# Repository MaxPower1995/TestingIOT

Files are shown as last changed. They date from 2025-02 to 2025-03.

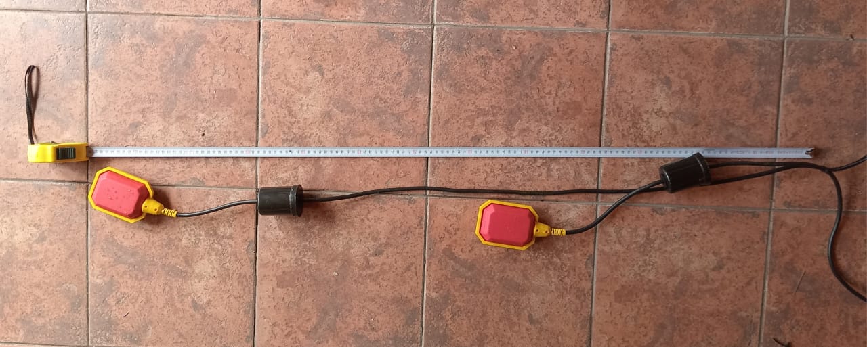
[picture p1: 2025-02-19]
Imagenes/Flotadores.jpeg

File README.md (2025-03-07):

# Modulo Zeus

# Versiones 
| Version | Fecha | Notas de la versión |
|---|---|---|
| 1.1 | 06/09/2024  | Versión de Alberto, agregue unos defines|
| 1.2 | 06/09/2024  | Arreglo el README.md |
| 1.3 | 10/10/2024 | Se cambia totalmente la logica |
| 1.4 | 26/11/2024 | Nivel de agua con flotadores |
| 1.5 | 27/11/2024 | Se agrega el aprpadeo del led |
| 1.6 | 27/11/2024 | Mayor robutez a la conexion WiFi |
| 1.7 | 29/11/2024 | Se arregla problema de prioridad en tareas |
| 1.8 | 29/11/2024 | Se agrega la lectura de los DS18B20 |
| 1.9 | 04/12/2024 | Se arregla nomenclatura de los sensores |
| 2.0 | 26/02/2025 | Server HTTP funcionando |

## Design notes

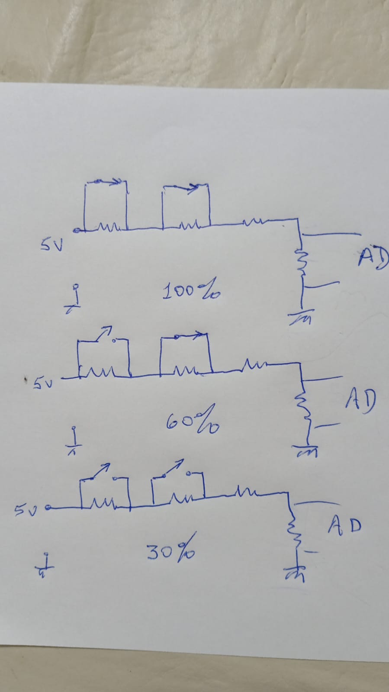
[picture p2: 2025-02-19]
Imagenes/LogicaNiveldeAguaADC.jpeg

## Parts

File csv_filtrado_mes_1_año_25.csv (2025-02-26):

Fecha | Hora | ubicacion | sensor | id | sector | estado | valor
2/1/25 | 03:39 | SE Morón | Temperatura | S3 | Temperatura Sala 2 Aires 3 y 4 | Alarmado | 27.20 °C
2/1/25 | 04:06 | SE Morón | Temperatura | S3 | Temperatura Sala 2 Aires 3 y 4 | desalarmado | 26.80 °C
2/1/25 | 04:22 | SE Morón | Temperatura | S3 | Temperatura Sala 2 Aires 3 y 4 | Alarmado | 27.20 °C
2/1/25 | 05:49 | SE Morón | Temperatura | S3 | Temperatura Sala 2 Aires 3 y 4 | desalarmado | 26.80 °C
2/1/25 | 09:02 | SE Morón | Temperatura | S3 | Temperatura Sala 2 Aires 3 y 4 | Alarmado | 27.20 °C
2/1/25 | 09:56 | SE Morón | Temperatura | S3 | Temperatura Sala 2 Aires 3 y 4 | desalarmado | 26.70 °C
2/1/25 | 10:13 | SE Morón | Temperatura | S3 | Temperatura Sala 2 Aires 3 y 4 | Alarmado | 27.20 °C
2/1/25 | 10:33 | SE Morón | Temperatura | S3 | Temperatura Sala 2 Aires 3 y 4 | desalarmado | 26.80 °C
2/1/25 | 11:20 | SE Morón | Temperatura | S3 | Temperatura Sala 2 Aires 3 y 4 | Alarmado | 27.20 °C
2/1/25 | 11:43 | SE Morón | Temperatura | S3 | Temperatura Sala 2 Aires 3 y 4 | desalarmado | 26.90 °C
2/1/25 | 11:59 | SE Morón | Temperatura | S3 | Temperatura Sala 2 Aires 3 y 4 | Alarmado | 27.20 °C
2/1/25 | 12:23 | SE Morón | Temperatura | S3 | Temperatura Sala 2 Aires 3 y 4 | desalarmado | 26.90 °C
2/1/25 | 12:39 | SE Morón | Temperatura | S3 | Temperatura Sala 2 Aires 3 y 4 | Alarmado | 27.10 °C
2/1/25 | 12:56 | SE Morón | Temperatura | S3 | Temperatura Sala 2 Aires 3 y 4 | desalarmado | 27.00 °C
2/1/25 | 13:13 | SE Morón | Temperatura | S3 | Temperatura Sala 2 Aires 3 y 4 | Alarmado | 27.30 °C
2/1/25 | 14:18 | SE Morón | Temperatura | S3 | Temperatura Sala 2 Aires 3 y 4 | desalarmado | 26.90 °C
4/1/25 | 09:16 | Ed. Libertador | Detector | S1 | ESTADO DEL GRUPO ELECTRÓGENO | Alarmado | ON
4/1/25 | 09:46 | Ed. Libertador | Detector | S1 | ESTADO DEL GRUPO ELECTRÓGENO | desalarmado | OFF
4/1/25 | 11:03 | Ed. Tronador | Detector | S1 | ESTADO DEL GRUPO ELECTRÓGENO | Alarmado | ON
4/1/25 | 11:21 | Ed. Tronador | Tensión | 24V | Voltaje Bateria | Alarmado | 28.77 V
4/1/25 | 11:32 | Ed. Tronador | Detector | S1 | ESTADO DEL GRUPO ELECTRÓGENO | desalarmado | OFF
6/1/25 | 10:39 | SE Edison | Detector | S1 | Puerta Sala de comunicaciones | Alarmado | OFF
6/1/25 | 11:58 | SE Edison | Detector | S1 | Puerta Sala de comunicaciones | desalarmado | ON
6/1/25 | 14:18 | SE Edison | Detector | S1 | Puerta Sala de comunicaciones | Alarmado | ON
6/1/25 | 23:54 | SE Morón | Tensión | Trifásica | Voltaje Fase T | Alarmado | 0.00 V
6/1/25 | 23:55 | SE Morón | Tensión | Trifásica | Voltaje fase R | Alarmado | 0.00 V
7/1/25 | 00:00 | SE Morón | Tensión | Trifásica | Voltaje Fase T | Alarmado | 0.00 V
7/1/25 | 00:00 | SE Morón | Tensión | Trifásica | Voltaje fase R | Alarmado | 0.00 V
7/1/25 | 00:02 | SE Edison | Detector | S1 | Puerta Sala de comunicaciones | Alarmado | ON
7/1/25 | 08:12 | SE San Alberto | Detector | S3 | Estado Aire Acondicionado 3 | Alarmado | OFF
7/1/25 | 09:53 | SE Morón | Detector | S3 | Estado Aire Acondicionado 3 | Alarmado | OFF
7/1/25 | 10:01 | SE San Alberto | Detector | S3 | Estado Aire Acondicionado 3 | desalarmado | ON
7/1/25 | 11:49 | SE San Alberto | Detector | S3 | Estado Aire Acondicionado 3 | Alarmado | OFF
7/1/25 | 12:17 | SE Morón | Detector | S2 | Estado Aire Acondicionado 2 | Alarmado | OFF
7/1/25 | 12:46 | SE San Alberto | Temperatura | S3 | Temperatura Sala 2 Aire 3 | Alarmado | 27.10 °C
7/1/25 | 13:10 | SE San Alberto | Detector | S3 | Estado Aire Acondicionado 3 | desalarmado | ON
7/1/25 | 13:13 | SE San Alberto | Temperatura | S3 | Temperatura Sala 2 Aire 3 | desalarmado | 26.20 °C
7/1/25 | 13:13 | SE Morón | Detector | S3 | Estado Aire Acondicionado 3 | desalarmado | ON
8/1/25 | 00:04 | SE Edison | Detector | S1 | Puerta Sala de comunicaciones | Alarmado | ON
8/1/25 | 00:04 | SE Morón | Detector | S2 | Estado Aire Acondicionado 2 | Alarmado | OFF
8/1/25 | 09:06 | SE Edison | Detector | S1 | Puerta Sala de comunicaciones | desalarmado | OFF
8/1/25 | 09:16 | SE Edison | Detector | S1 | Puerta Sala de comunicaciones | Alarmado | ON
8/1/25 | 09:33 | SE Edison | Detector | S1 | Puerta Sala de comunicaciones | desalarmado | OFF
11/1/25 | 08:08 | ED. Libertador | Detector | S1 | ESTADO DEL GRUPO ELECTRÓGENO | Alarmado | ON
11/1/25 | 08:34 | ED. Libertador | Detector | S1 | ESTADO DEL GRUPO ELECTRÓGENO | desalarmado | OFF
11/1/25 | 11:29 | SE Morón | Detector | S3 | Estado Aire Acondicionado 3 | Alarmado | OFF
11/1/25 | 11:29 | SE Morón | Detector | S4 | Estado Aire Acondicionado 4 | Alarmado | OFF
11/1/25 | 11:31 | SE Morón | Detector | S3 | Estado Aire Acondicionado 3 | desalarmado | ON
11/1/25 | 11:31 | SE Morón | Detector | S4 | Estado Aire Acondicionado 4 | desalarmado | ON
11/1/25 | 12:36 | SE Morón | Detector | S3 | Estado Aire Acondicionado 3 | Alarmado | OFF
11/1/25 | 12:36 | SE Morón | Detector | S4 | Estado Aire Acondicionado 4 | Alarmado | OFF
11/1/25 | 13:45 | SE Morón | Detector | S3 | Estado Aire Acondicionado 3 | desalarmado | ON
11/1/25 | 13:45 | SE Morón | Detector | S4 | Estado Aire Acondicionado 4 | desalarmado | ON
13/1/25 | 08:49 | SE Agronomia | Detector | S1 | ESTADO DEL GRUPO ELECTRÓGENO | Alarmado | ON
13/1/25 | 09:16 | SE Agronomia | Detector | S1 | ESTADO DEL GRUPO ELECTRÓGENO | desalarmado | OFF
13/1/25 | 17:24 | O.C. Merlo. | Tensión | Trifásica | Voltaje Fase R | Alarmado | 336.36 V
13/1/25 | 17:27 | O.C. Merlo. | Tensión | Trifásica | Voltaje Fase R | desalarmado | 389.37 V
14/1/25 | 00:25 | SE Morón | Temperatura | S3 | Temperatura Sala 2 Aires 3 y 4 | Alarmado | 27.10 °C
14/1/25 | 00:49 | SE Morón | Temperatura | S3 | Temperatura Sala 2 Aires 3 y 4 | desalarmado | 26.80 °C
14/1/25 | 01:08 | SE Morón | Temperatura | S3 | Temperatura Sala 2 Aires 3 y 4 | Alarmado | 27.20 °C
14/1/25 | 01:50 | SE Morón | Temperatura | S3 | Temperatura Sala 2 Aires 3 y 4 | desalarmado | 26.90 °C
14/1/25 | 02:06 | SE Morón | Temperatura | S3 | Temperatura Sala 2 Aires 3 y 4 | Alarmado | 27.20 °C
14/1/25 | 02:29 | SE Morón | Temperatura | S3 | Temperatura Sala 2 Aires 3 y 4 | desalarmado | 27.00 °C
14/1/25 | 02:46 | SE Morón | Temperatura | S3 | Temperatura Sala 2 Aires 3 y 4 | Alarmado | 27.10 °C
14/1/25 | 03:18 | SE Morón | Temperatura | S3 | Temperatura Sala 2 Aires 3 y 4 | desalarmado | 27.00 °C
14/1/25 | 03:34 | SE Morón | Temperatura | S3 | Temperatura Sala 2 Aires 3 y 4 | Alarmado | 27.10 °C
14/1/25 | 04:04 | SE Morón | Temperatura | S3 | Temperatura Sala 2 Aires 3 y 4 | desalarmado | 27.00 °C
14/1/25 | 04:23 | SE Morón | Temperatura | S3 | Temperatura Sala 2 Aires 3 y 4 | Alarmado | 27.60 °C
14/1/25 | 04:53 | SE Morón | Temperatura | S3 | Temperatura Sala 2 Aires 3 y 4 | desalarmado | 27.00 °C
14/1/25 | 05:10 | SE Morón | Temperatura | S3 | Temperatura Sala 2 Aires 3 y 4 | Alarmado | 27.10 °C
14/1/25 | 05:51 | SE Morón | Temperatura | S3 | Temperatura Sala 2 Aires 3 y 4 | desalarmado | 27.00 °C
14/1/25 | 06:08 | SE Morón | Temperatura | S3 | Temperatura Sala 2 Aires 3 y 4 | Alarmado | 27.10 °C
14/1/25 | 06:36 | SE Morón | Temperatura | S3 | Temperatura Sala 2 Aires 3 y 4 | desalarmado | 27.00 °C
14/1/25 | 06:53 | SE Morón | Temperatura | S3 | Temperatura Sala 2 Aires 3 y 4 | Alarmado | 27.20 °C
14/1/25 | 07:13 | SE Morón | Temperatura | S3 | Temperatura Sala 2 Aires 3 y 4 | desalarmado | 27.00 °C
14/1/25 | 07:32 | SE Morón | Temperatura | S3 | Temperatura Sala 2 Aires 3 y 4 | Alarmado | 27.10 °C
14/1/25 | 07:53 | SE Morón | Temperatura | S3 | Temperatura Sala 2 Aires 3 y 4 | desalarmado | 27.00 °C
14/1/25 | 08:09 | SE Morón | Temperatura | S3 | Temperatura Sala 2 Aires 3 y 4 | Alarmado | 27.20 °C
14/1/25 | 08:35 | SE Morón | Temperatura | S3 | Temperatura Sala 2 Aires 3 y 4 | desalarmado | 27.00 °C
14/1/25 | 08:51 | SE Morón | Temperatura | S3 | Temperatura Sala 2 Aires 3 y 4 | Alarmado | 27.10 °C
14/1/25 | 09:18 | SE Morón | Temperatura | S3 | Temperatura Sala 2 Aires 3 y 4 | desalarmado | 27.00 °C
14/1/25 | 09:35 | SE Morón | Temperatura | S3 | Temperatura Sala 2 Aires 3 y 4 | Alarmado | 27.10 °C
14/1/25 | 13:35 | SE Morón | Detector | S3 | Estado Aire Acondicionado 3 | Alarmado | OFF
14/1/25 | 13:35 | SE Morón | Detector | S4 | Estado Aire Acondicionado 4 | Alarmado | OFF
14/1/25 | 18:49 | SE Malaver | Temperatura | S3 | Temperatura Ambiente | Alarmado | 27.10 °C
14/1/25 | 19:31 | SE Malaver | Temperatura | S3 | Temperatura Ambiente | desalarmado | 26.80 °C
14/1/25 | 20:11 | SE Morón | Tensión | Trifásica | Voltaje Fase S | Alarmado | 0.00 V
14/1/25 | 20:12 | SE Morón | Tensión | Trifásica | Voltaje Fase T | Alarmado | 0.00 V
14/1/25 | 20:12 | SE Morón | Tensión | Trifásica | Voltaje fase R | Alarmado | 0.00 V
14/1/25 | 21:39 | SE Morón | Tensión | Trifásica | Voltaje Fase T | desalarmado | 398.54 V
14/1/25 | 21:39 | SE Morón | Tensión | Trifásica | Voltaje fase R | desalarmado | 393.18 V
14/1/25 | 21:40 | SE Morón | Tensión | Trifásica | Voltaje Fase S | desalarmado | 388.67 V
15/1/25 | 16:44 | SE Malaver | Temperatura | S3 | Temperatura Ambiente | Alarmado | 27.10 °C
16/1/25 | 00:00 | SE Malaver | Temperatura | S3 | Temperatura Ambiente | Alarmado | 27.10 °C
16/1/25 | 01:25 | SE Malaver | Temperatura | S3 | Temperatura Ambiente | desalarmado | 27.00 °C
18/1/25 | 09:32 | ED. Tronador | Detector | S1 | ESTADO DEL GRUPO ELECTRÓGENO | desalarmado | OFF
20/1/25 | 09:11 | SE San Alberto | Detector | S1 | Estado Aire Acondicionado 1 | Alarmado | OFF
20/1/25 | 09:11 | SE San Alberto | Detector | S3 | Estado Aire Acondicionado 3 | Alarmado | OFF
20/1/25 | 12:53 | SE San Alberto | Detector | S1 | Estado Aire Acondicionado 1 | desalarmado | ON
20/1/25 | 12:53 | SE San Alberto | Detector | S3 | Estado Aire Acondicionado 3 | desalarmado | ON
24/1/25 | 08:29 | SE San Alberto | Detector | S3 | Estado Aire Acondicionado 3 | Alarmado | OFF
24/1/25 | 08:58 | SE San Alberto | Detector | S3 | Estado Aire Acondicionado 3 | desalarmado | ON

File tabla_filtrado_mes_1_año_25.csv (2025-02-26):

fecha_inicio | hora_inicio | fecha_fin | hora_fin | ubicacion | sensor | id | sector | valor_inicio | valor_fin
02/01/25 | 03:39 | 02/01/25 | 14:18 | SE Morón | Temperatura | S3 | Temperatura Sala 2 Aires 3 y 4 | 27.20 °C | 26.90 °C
04/01/25 | 09:16 | 04/01/25 | 09:46 | Ed. Libertador | Detector | S1 | ESTADO DEL GRUPO ELECTRÓGENO | ON | OFF
04/01/25 | 11:03 | 04/01/25 | 11:32 | Ed. Tronador | Detector | S1 | ESTADO DEL GRUPO ELECTRÓGENO | ON | OFF
06/01/25 | 10:39 | 06/01/25 | 11:58 | SE Edison | Detector | S1 | Puerta Sala de comunicaciones | OFF | ON
07/01/25 | 08:12 | 07/01/25 | 13:10 | SE San Alberto | Detector | S3 | Estado Aire Acondicionado 3 | OFF | ON
07/01/25 | 12:46 | 07/01/25 | 13:13 | SE San Alberto | Temperatura | S3 | Temperatura Sala 2 Aire 3 | 27.10 °C | 26.20 °C
07/01/25 | 09:53 | 07/01/25 | 13:13 | SE Morón | Detector | S3 | Estado Aire Acondicionado 3 | OFF | ON
07/01/25 | 00:00 | N/A | N/A | SE Edison | Detector | S1 | Puerta Sala de comunicaciones | ON | N/A
08/01/25 | 00:00 | 08/01/25 | 09:33 | SE Edison | Detector | S1 | Puerta Sala de comunicaciones | ON | OFF
11/01/25 | 08:08 | 11/01/25 | 08:34 | ED. Libertador | Detector | S1 | ESTADO DEL GRUPO ELECTRÓGENO | ON | OFF
11/01/25 | 11:29 | 11/01/25 | 13:45 | SE Morón | Detector | S3 | Estado Aire Acondicionado 3 | OFF | ON
11/01/25 | 11:29 | 11/01/25 | 13:45 | SE Morón | Detector | S4 | Estado Aire Acondicionado 4 | OFF | ON
13/01/25 | 08:49 | 13/01/25 | 09:16 | SE Agronomia | Detector | S1 | ESTADO DEL GRUPO ELECTRÓGENO | ON | OFF
13/01/25 | 17:24 | 13/01/25 | 17:27 | O.C. Merlo. | Tensión | Trifásica | Voltaje Fase R | 336.36 V | 389.37 V
14/01/25 | 00:25 | 14/01/25 | 09:18 | SE Morón | Temperatura | S3 | Temperatura Sala 2 Aires 3 y 4 | 27.10 °C | 27.00 °C
14/01/25 | 18:49 | 14/01/25 | 19:31 | SE Malaver | Temperatura | S3 | Temperatura Ambiente | 27.10 °C | 26.80 °C
06/01/25 | 23:54 | N/A | N/A | SE Morón | Tensión | Trifásica | Voltaje Fase T | 0.00 V | N/A
07/01/25 | 00:00 | N/A | N/A | SE Morón | Tensión | Trifásica | Voltaje Fase T | 0.00 V | N/A
08/01/25 | 00:00 | N/A | N/A | SE Morón | Tensión | Trifásica | Voltaje Fase T | 0.00 V | N/A
09/01/25 | 00:00 | N/A | N/A | SE Morón | Tensión | Trifásica | Voltaje Fase T | 0.00 V | N/A
10/01/25 | 00:00 | N/A | N/A | SE Morón | Tensión | Trifásica | Voltaje Fase T | 0.00 V | N/A
11/01/25 | 00:00 | N/A | N/A | SE Morón | Tensión | Trifásica | Voltaje Fase T | 0.00 V | N/A
12/01/25 | 00:00 | N/A | N/A | SE Morón | Tensión | Trifásica | Voltaje Fase T | 0.00 V | N/A
13/01/25 | 00:00 | N/A | N/A | SE Morón | Tensión | Trifásica | Voltaje Fase T | 0.00 V | N/A
14/01/25 | 00:00 | 14/01/25 | 21:39 | SE Morón | Tensión | Trifásica | Voltaje Fase T | 0.00 V | 398.54 V
06/01/25 | 23:55 | N/A | N/A | SE Morón | Tensión | Trifásica | Voltaje fase R | 0.00 V | N/A
07/01/25 | 00:00 | N/A | N/A | SE Morón | Tensión | Trifásica | Voltaje fase R | 0.00 V | N/A
08/01/25 | 00:00 | N/A | N/A | SE Morón | Tensión | Trifásica | Voltaje fase R | 0.00 V | N/A
09/01/25 | 00:00 | N/A | N/A | SE Morón | Tensión | Trifásica | Voltaje fase R | 0.00 V | N/A
10/01/25 | 00:00 | N/A | N/A | SE Morón | Tensión | Trifásica | Voltaje fase R | 0.00 V | N/A
11/01/25 | 00:00 | N/A | N/A | SE Morón | Tensión | Trifásica | Voltaje fase R | 0.00 V | N/A
12/01/25 | 00:00 | N/A | N/A | SE Morón | Tensión | Trifásica | Voltaje fase R | 0.00 V | N/A
13/01/25 | 00:00 | N/A | N/A | SE Morón | Tensión | Trifásica | Voltaje fase R | 0.00 V | N/A
14/01/25 | 00:00 | 14/01/25 | 21:39 | SE Morón | Tensión | Trifásica | Voltaje fase R | 0.00 V | 393.18 V
14/01/25 | 20:11 | 14/01/25 | 21:40 | SE Morón | Tensión | Trifásica | Voltaje Fase S | 0.00 V | 388.67 V
15/01/25 | 16:44 | N/A | N/A | SE Malaver | Temperatura | S3 | Temperatura Ambiente | 27.10 °C | N/A
16/01/25 | 00:00 | 16/01/25 | 01:25 | SE Malaver | Temperatura | S3 | Temperatura Ambiente | 27.10 °C | 27.00 °C
20/01/25 | 09:11 | 20/01/25 | 12:53 | SE San Alberto | Detector | S1 | Estado Aire Acondicionado 1 | OFF | ON
20/01/25 | 09:11 | 20/01/25 | 12:53 | SE San Alberto | Detector | S3 | Estado Aire Acondicionado 3 | OFF | ON
24/01/25 | 08:29 | 24/01/25 | 08:58 | SE San Alberto | Detector | S3 | Estado Aire Acondicionado 3 | OFF | ON
04/01/25 | 11:21 | N/A | N/A | Ed. Tronador | Tensión | 24V | Voltaje Bateria | 28.77 V | N/A
07/01/25 | 12:17 | N/A | N/A | SE Morón | Detector | S2 | Estado Aire Acondicionado 2 | OFF | N/A
14/01/25 | 13:35 | N/A | N/A | SE Morón | Detector | S3 | Estado Aire Acondicionado 3 | OFF | N/A
14/01/25 | 13:35 | N/A | N/A | SE Morón | Detector | S4 | Estado Aire Acondicionado 4 | OFF | N/A

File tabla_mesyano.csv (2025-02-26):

Fecha Inicio | Hora Inicio | Fecha Fin | Hora Fin | ubicacion | sensor | id | sector | valor
11/1/25 | 08:08 | 11/1/25 | 08:34 | ED. Libertador | Detector | S1 | ESTADO DEL GRUPO ELECTRÓGENO | ON
4/1/25 | 09:16 | 4/1/25 | 09:46 | Ed. Libertador | Detector | S1 | ESTADO DEL GRUPO ELECTRÓGENO | ON
4/1/25 | 11:03 | 4/1/25 | 11:32 | Ed. Tronador | Detector | S1 | ESTADO DEL GRUPO ELECTRÓGENO | ON
4/1/25 | 11:21 | - | - | Ed. Tronador | Tensión | 24V | Voltaje Bateria | 28.77 V
13/1/25 | 17:24 | 13/1/25 | 17:27 | O.C. Merlo. | Tensión | Trifásica | Voltaje Fase R | 336.36 V
13/1/25 | 08:49 | 13/1/25 | 09:16 | SE Agronomia | Detector | S1 | ESTADO DEL GRUPO ELECTRÓGENO | ON
6/1/25 | 10:39 | 6/1/25 | 11:58 | SE Edison | Detector | S1 | Puerta Sala de comunicaciones | OFF
6/1/25 | 14:18 | 8/1/25 | 09:06 | SE Edison | Detector | S1 | Puerta Sala de comunicaciones | ON
7/1/25 | 00:02 | 8/1/25 | 09:33 | SE Edison | Detector | S1 | Puerta Sala de comunicaciones | ON
8/1/25 | 00:04 | - | - | SE Edison | Detector | S1 | Puerta Sala de comunicaciones | ON
8/1/25 | 09:16 | - | - | SE Edison | Detector | S1 | Puerta Sala de comunicaciones | ON
14/1/25 | 18:49 | 14/1/25 | 19:31 | SE Malaver | Temperatura | S3 | Temperatura Ambiente | 27.10 °C
15/1/25 | 16:44 | 16/1/25 | 01:25 | SE Malaver | Temperatura | S3 | Temperatura Ambiente | 27.10 °C
16/1/25 | 00:00 | - | - | SE Malaver | Temperatura | S3 | Temperatura Ambiente | 27.10 °C
7/1/25 | 12:17 | - | - | SE Morón | Detector | S2 | Estado Aire Acondicionado 2 | OFF
8/1/25 | 00:04 | - | - | SE Morón | Detector | S2 | Estado Aire Acondicionado 2 | OFF
7/1/25 | 09:53 | 7/1/25 | 13:13 | SE Morón | Detector | S3 | Estado Aire Acondicionado 3 | OFF
11/1/25 | 11:29 | 11/1/25 | 11:31 | SE Morón | Detector | S3 | Estado Aire Acondicionado 3 | OFF
11/1/25 | 12:36 | 11/1/25 | 13:45 | SE Morón | Detector | S3 | Estado Aire Acondicionado 3 | OFF
14/1/25 | 13:35 | - | - | SE Morón | Detector | S3 | Estado Aire Acondicionado 3 | OFF
11/1/25 | 11:29 | 11/1/25 | 11:31 | SE Morón | Detector | S4 | Estado Aire Acondicionado 4 | OFF
11/1/25 | 12:36 | 11/1/25 | 13:45 | SE Morón | Detector | S4 | Estado Aire Acondicionado 4 | OFF
14/1/25 | 13:35 | - | - | SE Morón | Detector | S4 | Estado Aire Acondicionado 4 | OFF
2/1/25 | 03:39 | 2/1/25 | 04:06 | SE Morón | Temperatura | S3 | Temperatura Sala 2 Aires 3 y 4 | 27.20 °C
2/1/25 | 04:22 | 2/1/25 | 05:49 | SE Morón | Temperatura | S3 | Temperatura Sala 2 Aires 3 y 4 | 27.20 °C
2/1/25 | 09:02 | 2/1/25 | 09:56 | SE Morón | Temperatura | S3 | Temperatura Sala 2 Aires 3 y 4 | 27.20 °C
2/1/25 | 10:13 | 2/1/25 | 10:33 | SE Morón | Temperatura | S3 | Temperatura Sala 2 Aires 3 y 4 | 27.20 °C
2/1/25 | 11:20 | 2/1/25 | 11:43 | SE Morón | Temperatura | S3 | Temperatura Sala 2 Aires 3 y 4 | 27.20 °C
2/1/25 | 11:59 | 2/1/25 | 12:23 | SE Morón | Temperatura | S3 | Temperatura Sala 2 Aires 3 y 4 | 27.20 °C
2/1/25 | 12:39 | 2/1/25 | 12:56 | SE Morón | Temperatura | S3 | Temperatura Sala 2 Aires 3 y 4 | 27.10 °C
2/1/25 | 13:13 | 2/1/25 | 14:18 | SE Morón | Temperatura | S3 | Temperatura Sala 2 Aires 3 y 4 | 27.30 °C
14/1/25 | 00:25 | 14/1/25 | 00:49 | SE Morón | Temperatura | S3 | Temperatura Sala 2 Aires 3 y 4 | 27.10 °C
14/1/25 | 01:08 | 14/1/25 | 01:50 | SE Morón | Temperatura | S3 | Temperatura Sala 2 Aires 3 y 4 | 27.20 °C
14/1/25 | 02:06 | 14/1/25 | 02:29 | SE Morón | Temperatura | S3 | Temperatura Sala 2 Aires 3 y 4 | 27.20 °C
14/1/25 | 02:46 | 14/1/25 | 03:18 | SE Morón | Temperatura | S3 | Temperatura Sala 2 Aires 3 y 4 | 27.10 °C
14/1/25 | 03:34 | 14/1/25 | 04:04 | SE Morón | Temperatura | S3 | Temperatura Sala 2 Aires 3 y 4 | 27.10 °C
14/1/25 | 04:23 | 14/1/25 | 04:53 | SE Morón | Temperatura | S3 | Temperatura Sala 2 Aires 3 y 4 | 27.60 °C
14/1/25 | 05:10 | 14/1/25 | 05:51 | SE Morón | Temperatura | S3 | Temperatura Sala 2 Aires 3 y 4 | 27.10 °C
14/1/25 | 06:08 | 14/1/25 | 06:36 | SE Morón | Temperatura | S3 | Temperatura Sala 2 Aires 3 y 4 | 27.10 °C
14/1/25 | 06:53 | 14/1/25 | 07:13 | SE Morón | Temperatura | S3 | Temperatura Sala 2 Aires 3 y 4 | 27.20 °C
14/1/25 | 07:32 | 14/1/25 | 07:53 | SE Morón | Temperatura | S3 | Temperatura Sala 2 Aires 3 y 4 | 27.10 °C
14/1/25 | 08:09 | 14/1/25 | 08:35 | SE Morón | Temperatura | S3 | Temperatura Sala 2 Aires 3 y 4 | 27.20 °C
14/1/25 | 08:51 | 14/1/25 | 09:18 | SE Morón | Temperatura | S3 | Temperatura Sala 2 Aires 3 y 4 | 27.10 °C
14/1/25 | 09:35 | - | - | SE Morón | Temperatura | S3 | Temperatura Sala 2 Aires 3 y 4 | 27.10 °C
6/1/25 | 23:54 | 14/1/25 | 21:39 | SE Morón | Tensión | Trifásica | Voltaje Fase T | 0.00 V
6/1/25 | 23:55 | 14/1/25 | 21:40 | SE Morón | Tensión | Trifásica | Voltaje fase R | 0.00 V
7/1/25 | 00:00 | - | - | SE Morón | Tensión | Trifásica | Voltaje Fase T | 0.00 V
7/1/25 | 00:00 | - | - | SE Morón | Tensión | Trifásica | Voltaje fase R | 0.00 V
14/1/25 | 20:11 | - | - | SE Morón | Tensión | Trifásica | Voltaje Fase S | 0.00 V
14/1/25 | 20:12 | - | - | SE Morón | Tensión | Trifásica | Voltaje Fase T | 0.00 V
14/1/25 | 20:12 | - | - | SE Morón | Tensión | Trifásica | Voltaje fase R | 0.00 V
20/1/25 | 09:11 | 20/1/25 | 12:53 | SE San Alberto | Detector | S1 | Estado Aire Acondicionado 1 | OFF
7/1/25 | 08:12 | 7/1/25 | 10:01 | SE San Alberto | Detector | S3 | Estado Aire Acondicionado 3 | OFF
7/1/25 | 11:49 | 7/1/25 | 13:10 | SE San Alberto | Detector | S3 | Estado Aire Acondicionado 3 | OFF
20/1/25 | 09:11 | 20/1/25 | 12:53 | SE San Alberto | Detector | S3 | Estado Aire Acondicionado 3 | OFF
24/1/25 | 08:29 | 24/1/25 | 08:58 | SE San Alberto | Detector | S3 | Estado Aire Acondicionado 3 | OFF
7/1/25 | 12:46 | 7/1/25 | 13:13 | SE San Alberto | Temperatura | S3 | Temperatura Sala 2 Aire 3 | 27.10 °C

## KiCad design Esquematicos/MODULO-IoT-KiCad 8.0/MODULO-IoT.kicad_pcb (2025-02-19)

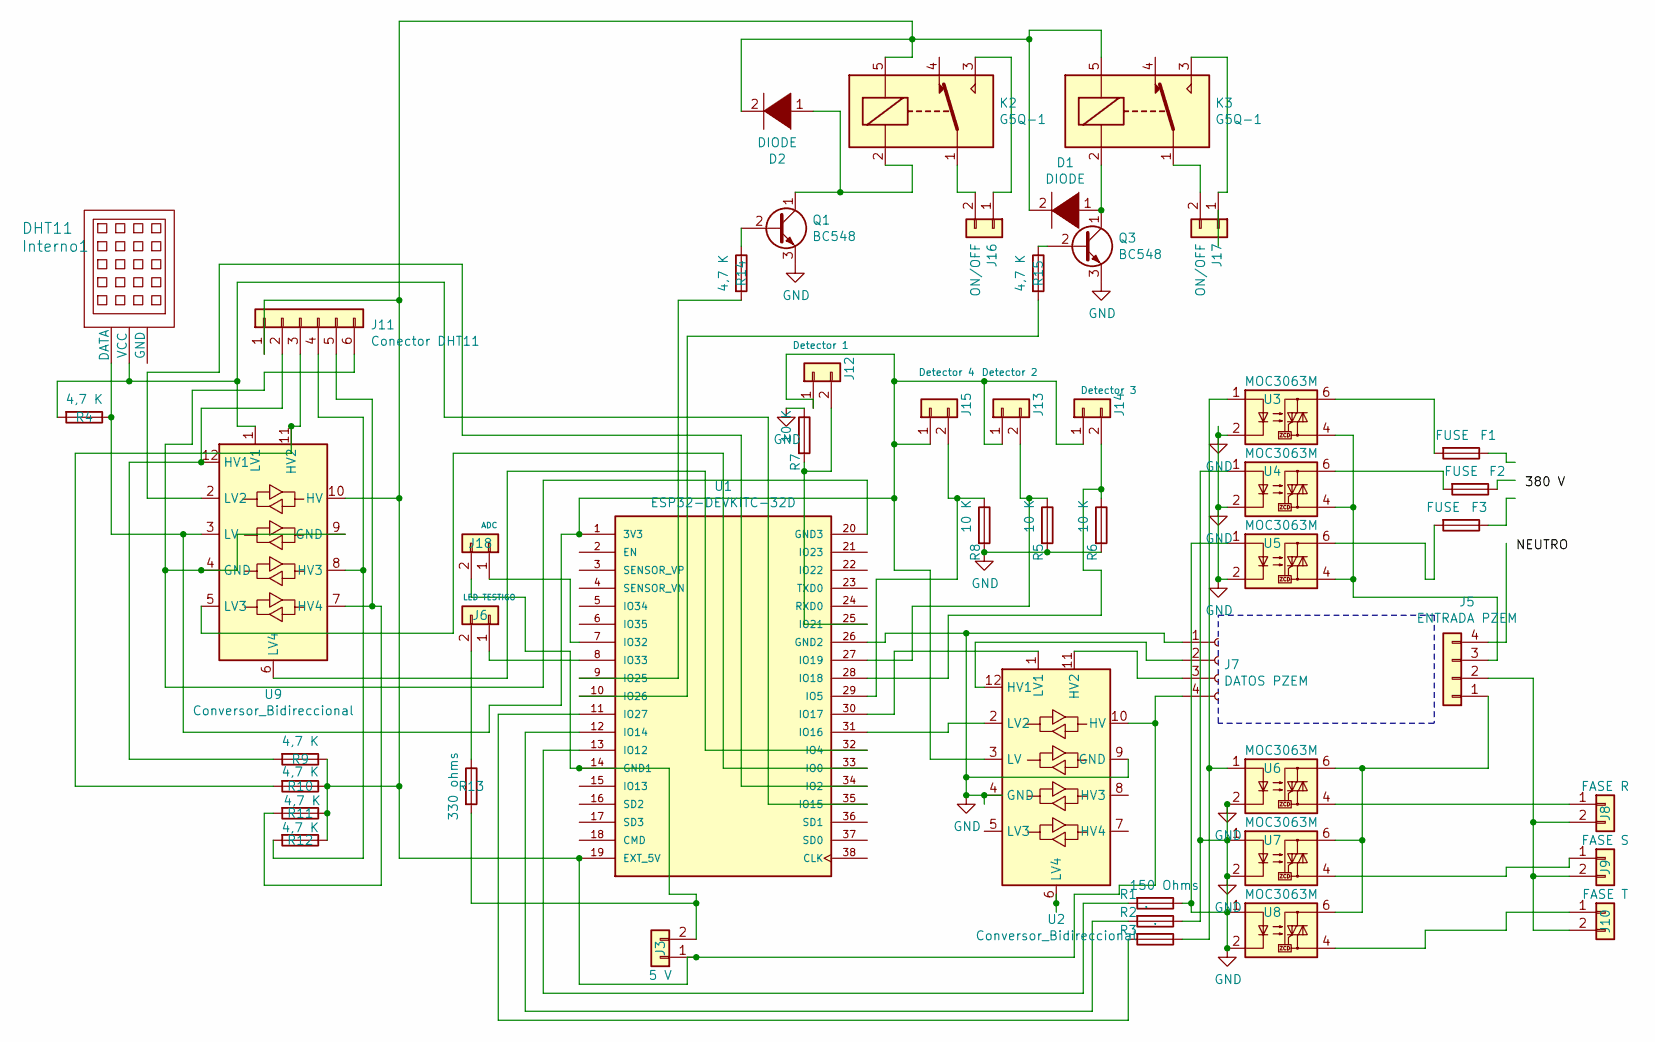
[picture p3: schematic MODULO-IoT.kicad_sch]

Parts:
D1, D2: DIODE; D_A-405_P2.54mm_Vertical_AnodeUp
F1, F2, F3: FUSE; Fuse_Bourns_MF-RG300
Interno1: DHT11; Aosong_DHT11_5.5x12.0_P2.54mm
J3: 5 V; PinHeader_1x02_P2.54mm_Vertical
J5: ENTRADA PZEM; TerminalBlock_Phoenix_MKDS-1,5-4-5.08_1x04_P5.08mm_Horizont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
J6: LED TESTIGO; PinHeader_1x02_P2.54mm_Vertical
J7: DATOS PZEM; PinHeader_1x04_P2.54mm_Vertical
J8: FASE R; TerminalBlock_Phoenix_MKDS-1,5-2-5.08_1x02_P5.08mm_Horizont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
J9: FASE S; TerminalBlock_Phoenix_MKDS-1,5-2-5.08_1x02_P5.08mm_Horizont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
J10: FASE T; TerminalBlock_Phoenix_MKDS-1,5-2-5.08_1x02_P5.08mm_Horizont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
J11: Conector DHT11; TerminalBlock_Phoenix_MKDS-1,5-6_1x06_P5.00mm_Horizontal
J12: Detector 1; TerminalBlock_Phoenix_MKDS-1,5-2-5.08_1x02_P5.08mm_Horizont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
J13: Detector 2; TerminalBlock_Phoenix_MKDS-1,5-2-5.08_1x02_P5.08mm_Horizont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
J14: Detector 3; TerminalBlock_Phoenix_MKDS-1,5-2-5.08_1x02_P5.08mm_Horizont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
J15: Detector 4; TerminalBlock_Phoenix_MKDS-1,5-2-5.08_1x02_P5.08mm_Horizont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
J16, J17: ON/OFF; TerminalBlock_Phoenix_MKDS-1,5-2-5.08_1x02_P5.08mm_Horizont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
J18: ADC; PinHeader_1x02_P2.54mm_Vertical
K2, K3: G5Q-1; Relay_SPDT_Omron-G5LE-1
Q1, Q3: BC548; TO-126-3_Vertical
R1: 150 Ohms; R_Axial_DIN0207_L6.3mm_D2.5mm_P10.16mm_Horizontal
R2, R3: .; R_Axial_DIN0207_L6.3mm_D2.5mm_P10.16mm_Horizontal
R4, R9, R10, R11, R12, R14, R15: 4,7 K; R_Axial_DIN0309_L9.0mm_D3.2mm_P5.08mm_Vertical
R5, R6, R7, R8: 10 K; R_Axial_DIN0207_L6.3mm_D2.5mm_P10.16mm_Horizontal
R13: 330 ohms; R_Axial_DIN0309_L9.0mm_D3.2mm_P5.08mm_Vertical
U1: ESP32-DEVKITC-32D; MODULE_ESP32-DEVKITC-32D
U2, U9: Conversor_Bidireccional; DIP-12_W10.16mm_LongPads
U3, U4, U5, U6, U7, U8: MOC3063M; DIP-6_W7.62mm

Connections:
GND: J7.1, Q1.3 (E), Q3.3 (E), R1.1, R2.1, R5.2, R6.2, R7.1, R8.2, U1.26 (GND2), U2.4 (GND), U2.9 (GND), U3.2, U4.1, U4.2, U5.1, U5.2, U6.2, U7.1, U7.2, U8.1, U8.2
unnamed: D1.2 (A), D2.2 (A), J3.1, J7.4, J11.1, K2.5, K3.5, R9.1, R10.1, R11.1, R12.1, U1.19 (EXT_5V), U2.10 (HV), U9.10 (HV)
unnamed: D1.1 (K), K3.2, Q3.1 (C)
unnamed: D2.1 (K), K2.2, Q1.1 (C)
unnamed: F1.2, U3.6
unnamed: F2.2, U4.6
unnamed: F3.2, U5.6
unnamed: Interno1.1 (DATA), J12.1, J13.1, J14.1, J15.1, R4.1, U1.1 (3V3), U2.3 (LV), U9.3 (LV)
unnamed: Interno1.2 (VCC), R4.2, U1.35 (IO15), U9.1 (LV1)
unnamed: J5.1, U6.6, U7.6, U8.6
unnamed: J5.3, U3.4, U4.4, U5.4
unnamed: J6.1, U1.8 (IO33)
unnamed: J6.2, R13.1
unnamed: J7.2, U2.12 (HV1)
unnamed: J7.3, U2.11 (HV2)
unnamed: J8.1, U6.4
unnamed: J9.1, U7.4
unnamed: J10.1, U8.4
unnamed: J5.2, J8.2, J9.2, J10.2
unnamed: J11.2, R9.2, U9.12 (HV1)
unnamed: J11.3, R10.2, U9.11 (HV2)
unnamed: J11.4, R12.2, U9.8 (HV3)
unnamed: J11.5, R11.2, U9.7 (HV4)
unnamed: J11.6, U1.20 (GND3), U9.4 (GND), U9.9 (GND)
unnamed: J12.2, R7.2, U1.25 (IO21)
unnamed: J13.2, R5.1, U1.27 (IO19)
unnamed: J14.2, R6.1, U1.28 (IO18)
unnamed: J15.2, R8.1, U1.29 (IO5)
unnamed: J16.1, K2.3
unnamed: J16.2, K2.1
unnamed: J17.1, K3.3
unnamed: J17.2, K3.1
unnamed: J18.1, U1.7 (IO32)
unnamed: J3.2, J18.2, R13.2, U1.14 (GND1)
unnamed: Q1.2 (B), R14.1
unnamed: Q3.2 (B), R15.1
unnamed: R3.1, U3.1, U6.1
unnamed: U1.33 (IO0), U9.5 (LV3)
unnamed: U1.34 (IO2), U9.2 (LV2)
unnamed: U1.32 (IO4), U9.6 (LV4)
unnamed: R1.2, U1.13 (IO12)
unnamed: R2.2, U1.12 (IO14)
unnamed: U1.31 (IO16), U2.2 (LV2)
unnamed: U1.30 (IO17), U2.1 (LV1)
unnamed: R14.2, U1.9 (IO25)
unnamed: R15.2, U1.10 (IO26)
unnamed: R3.2, U1.11 (IO27)

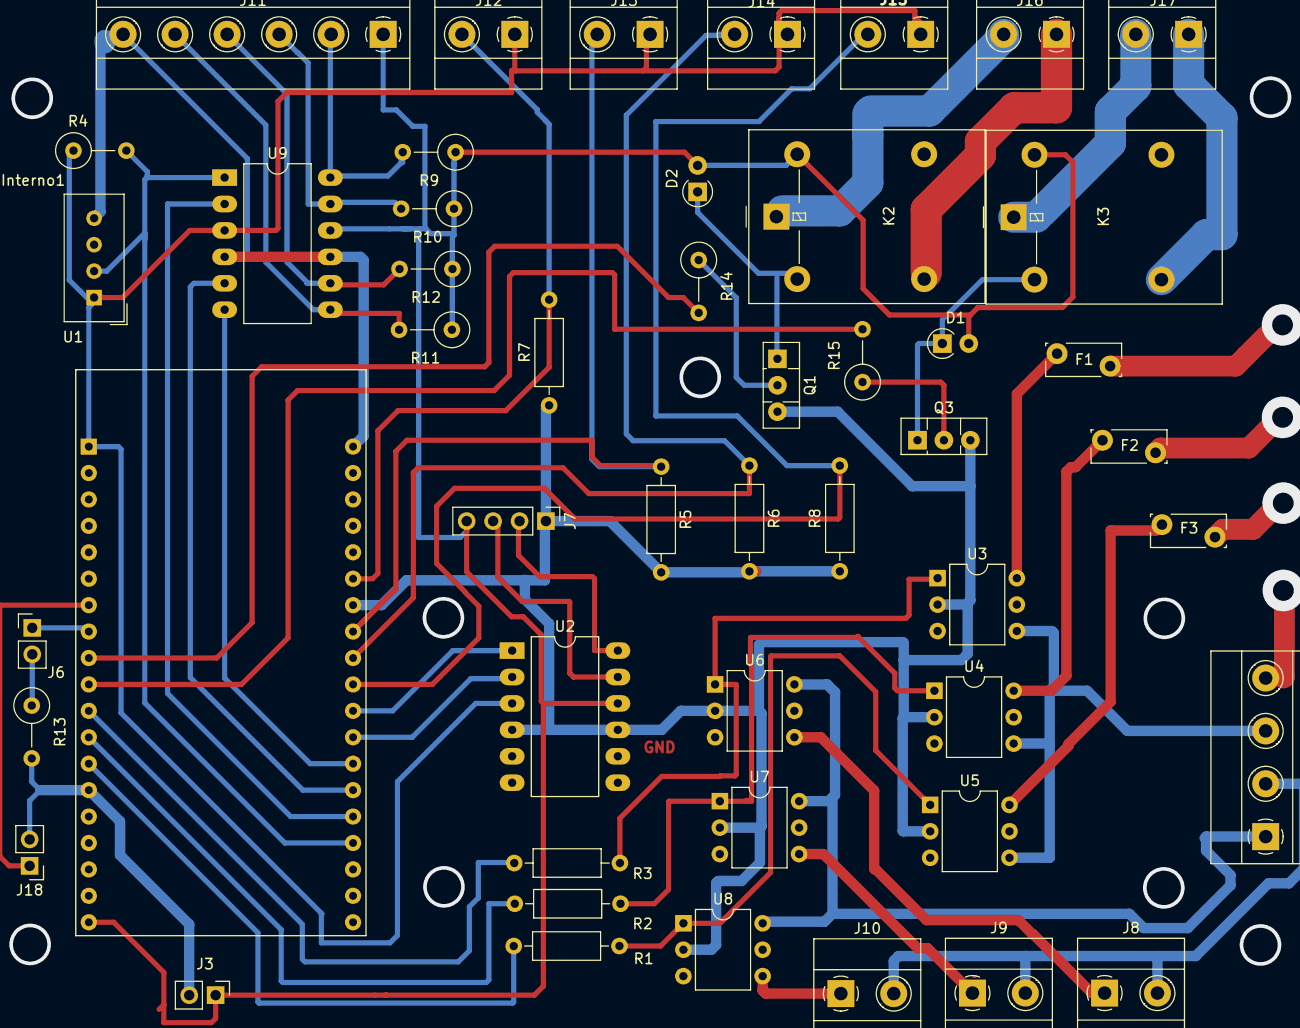
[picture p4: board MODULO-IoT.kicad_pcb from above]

Board: 2 copper layers, 49 parts (0 on the bottom side), 47 nets.

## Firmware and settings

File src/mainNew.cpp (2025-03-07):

#include <Arduino.h>
#include <WiFi.h>
#include <WebServer.h>
#include <Preferences.h>
#include "htmlpage.hpp"
#include <PubSubClient.h>
#include "DHT.h"
#include <PZEM004Tv30.h>
#include <OneWire.h>
#include <DallasTemperature.h>
#include "Adafruit_MQTT.h"
#include "Adafruit_MQTT_Client.h"
#include <string>

// Definir el GPIO para activar el modo AP
#define CONFIG_PIN 4
#define DHT1 15 //15
#define DHT2 2
#define DHT3 0
#define DHT4 4

#define DETECTOR_1 5
#define DETECTOR_2 18
#define DETECTOR_3 19
#define DETECTOR_4 21

#define DHTTYPE DHT11   // DHT 11
#define DHTTYPE2 DHT11   // DHT 11-2
#define DHTTYPE3 DHT11   // DHT 11-3
#define DHTTYPE4 DHT11   // DHT 11-4

#define PZEM_RX_PIN 16
#define PZEM_TX_PIN 17
#define PZEM_SERIAL Serial2

#define RELE_1 25
#define RELE_2 26
#define ADC_1 32
#define ADC_2 36

#define FASE_R 12
#define FASE_S 14
#define FASE_T 27
#define LED_ROJO 33

//El largo de este vector como minimo tiene que ser el tiempo de envio en segundos x2, porque leo los detectores cada 500ms
#define VECTOR_DETECTOR 250 
#define VECTOR 4
#define ERROR 0

#define RANGO_INF 0
#define RANGO_SUP 100

// HTML almacenado en un string (ya lo definimos antes)
extern const char htmlPage[];
extern WebServer server;
extern Preferences preferences;
extern Config config;  // Variable global para almacenar la configuración
PZEM004Tv30 pzem(PZEM_SERIAL, PZEM_RX_PIN, PZEM_TX_PIN);

DHT dht1(DHT1, DHTTYPE);
DHT dht2(DHT2, DHTTYPE2);
DHT dht3(DHT3, DHTTYPE3);
DHT dht4(DHT4, DHTTYPE4);

OneWire oneWire1(DHT1);
OneWire oneWire2(DHT2);
OneWire oneWire3(DHT3);
OneWire oneWire4(DHT4);

DallasTemperature sensors1(&oneWire1);
DallasTemperature sensors2(&oneWire2);
DallasTemperature sensors3(&oneWire3);
DallasTemperature sensors4(&oneWire4);

//Incluir la direccion del servidor MQTT
const char* mqtt_server = "143.198.66.52";// Broker EDENOR
//const char* mqtt_server = "143.244.186.22"; // Broker Prueba
const char* mqtt_user = "emsetec";
const char* mqtt_pass = "84705200";

//Variables para enviar datos por MQTT
const unsigned long TIEMPO_DE_ENVIO = 60000;  
const unsigned long RESET = 3600000*2;  // 1 hora en milisegundos
unsigned long ultimoEnvio = 0;  // Tiempo de la última ejecución
unsigned long tiempoActual = 0;
unsigned long tiempoReset = 0;

//Variables de Funcionamiento
float factorVoltaje = 1;
float voltaje[3] = {0,0,0};
float corriente[3] = {0,0,0};
float temperatura[4] = {0,0,0,0};
float humedad[4] = {0,0,0,0};
float adc[4] = {0,0,0,0};
float factorBobina = 1;

int maxWifiSSID = 4;
int maxWifiRetry = 10;
String CLIENT_ID;
String EQUIPO;

#define ESP_CLIENT_NAME espClient
WiFiClient ESP_CLIENT_NAME;
PubSubClient client(ESP_CLIENT_NAME);


const char* redes[4][2] = {
    {"e-Invitados", "Edenor2022$"},
    {"EMSETEC4G", "IOT2024EMSETEC"},
    {"EMSETEC-2.4GHz", "33710081099"},
    {"HUAWEI_311_1B94", "Maxpower1995"}
  };

//Funciones
void wifiInit(const char* redes[][2], int num_redes, int max_intentos);
void lecturaPzems();
void enviarDatosMQTT();
void parpadearLed(void *pvParameters);
void reconnect();
void leerDHT11();
void leerDS18B20();
void configuracionPines();

// ########################################################################################################################
// ################## MEJORAS PARA EL SISTEMA #############################################################################
// ########################################################################################################################

// ----> Tengo que ponerle un temporizador para que no quede siempre en modo AP, nose 5 minutos
// ----> Agregar la red del laboratorio
// ----> Para seleccionar los adcs, quiza me convenga usar un if en el setup y despues un SWITCH/Diccionario
// ----> sprintf(topicBuffer, "EMSETEC/%s/SENSOR1/HUMEDAD", EQUIPO.c_str());, guardaro en un string en el setup  asi no ejecuta multiples veces lo mismo

// ########################################################################################################################
// ########################################################################################################################
// ########################################################################################################################

void setup() {
  Serial.begin(115200);
  delay(200);
  pinMode(CONFIG_PIN, INPUT_PULLUP);
  Serial.println("#######################################");
  Serial.println("    Incicializando el Sistema...");
  Serial.println("#######################################");
  loadConfiguration();
  configuracionPines();
  //printConfiguration();

  EQUIPO = "SERIE" + String(config.serialNumber);
  CLIENT_ID = "espClient"+ String(config.serialNumber);


  // Si el pin de configuración está en alto, entra en modo AP
  if (digitalRead(CONFIG_PIN) == LOW) {
    startAP();
    server.on("/", handleRoot);
    server.on("/save", handleSave);
    server.begin();
    Serial.println("Servidor web iniciado en modo AP.");
  } else {
    Serial.println("Modo normal. No se inicia configuración.");
    // Aquí podrías cargar la configuración y conectar a WiFi, etc.
    //loadConfiguration();
    //printConfiguration();
  }

  if (config.sensor == "DHT11") {
    dht1.begin();dht2.begin();
    dht3.begin();dht4.begin();
    Serial.println("Se usan: DHT11");
  } else if (config.sensor == "DS18B20") {
    sensors1.begin();sensors2.begin();
    sensors3.begin();sensors4.begin();   
    Serial.println("Se usan: DS18B20"); 
  } else {
    Serial.println("No se mide Temperatura");
  }

  if (config.conexion == "Trifasica") {
    factorVoltaje = sqrt(3);
    Serial.println("Se mide tension Trifásica");
  } else if (config.conexion == "Monofasica") {
    factorVoltaje = 1; 
    Serial.println("Se mide tension Monofásica");
  } else {
    Serial.println("No se mide Tensión");
  }

  factorBobina = config.factor;
  Serial.print("Factor de Bobina: ");
  Serial.println(factorBobina);

  // Imprime el valor del define
  Serial.print("Este es el Modulo: ");
  Serial.println(EQUIPO);
  Serial.print("Con el Cliente: ");
  Serial.println(CLIENT_ID);

  if (strcmp(mqtt_server, "143.198.66.52") == 0) {
    Serial.println("Conectado al Broker de EDENOR");
  } else {
    Serial.println("Conectado al Broker de PRUEBAS");
  }
  
  client.setServer(mqtt_server, 1884);
  //xTaskCreate(leerDetectores,"Leer Detectores",4096,NULL,1,NULL);
  xTaskCreate(parpadearLed, "Blink Task", 4096, NULL, 0, NULL);
  //resetVectorDetectores();
  //analogReadResolution(12);
  Serial.println("#######################################");
  Serial.println("        Sistema Configurado");
  Serial.println("#######################################");
}


void loop() {
  tiempoReset = millis();
  if(tiempoReset >= RESET){
    ESP.restart();
  }
  tiempoActual = millis();

  if (WiFi.getMode() == WIFI_AP) {
    server.handleClient();
  }else{
    // Aquí el resto de la lógica del dispositivo...
    if (WiFi.status() != WL_CONNECTED) {
      wifiInit(redes, maxWifiSSID, maxWifiRetry);
    }

    Serial.println("Leyendo los Pzems");
    lecturaPzems();
    if (config.sensor == "DHT11") {
      leerDHT11();
      Serial.println("Leyendo DHT11");
    } else if (config.sensor == "DS18B20") {
      leerDS18B20(); 
      Serial.println("Leyendo DS18B20"); 
    } else {
      Serial.println("No se mide Temperatura");
    }
    enviarDatosMQTT();
  }


// ------------ Automatizaciones ADC 1 ------------
  if (config.adc1 == "Combustible") {
    Serial.println("Se lee Combustible en el ADC1");
    adc[0] = analogRead(ADC_1);
  } else if (config.adc1 == "Bateria 12") {
    Serial.println("Se lee Bateria 12V en el ADC1");
    adc[0] = analogRead(ADC_1);
  } else if (config.adc1 == "Bateria 24") {
    Serial.println("Se lee Bateria 24V en el ADC1");
    adc[0] = analogRead(ADC_1);
  } else if (config.adc1 == "Nivel Inundacion") {
    Serial.println("Se lee Bateria 36V en el ADC1");
    adc[0] = analogRead(ADC_1);
  }else {
    Serial.println("No se mide ADC1");
  }

// ------------ Automatizaciones ADC 2 ------------
  if (config.adc2 == "Combustible") {
    Serial.println("Se lee Combustible en el ADC2");
    adc[0] = analogRead(ADC_2);
  } else if (config.adc2 == "Bateria 12") {
    Serial.println("Se lee Bateria 12V en el ADC2");
    adc[0] = analogRead(ADC_2);
  } else if (config.adc2 == "Bateria 24") {
    Serial.println("Se lee Bateria 24V en el ADC2");
    adc[0] = analogRead(ADC_2);
  } else if (config.adc2 == "Nivel Inundacion") {
    Serial.println("Se lee Bateria 36V en el ADC1");
    adc[0] = analogRead(ADC_2);
  }else {
    Serial.println("No se mide ADC2");
  }

}

  //---------------- VOID CONECTAR WiFi -------------------
void wifiInit(const char* redes[][2], int numRedes, int max_intentos) {
  Serial.println("Iniciando conexión WiFi...");
  bool conectado = false;
  preferences.begin("wifi", false); // Iniciar NVS para guardar/leer datos

  String last_ssid = preferences.getString("last_ssid", "");
  String last_password = preferences.getString("last_password", "");
  preferences.end();

  

  // Si hay una red guardada, intenta conectarte primero a ella
  if (last_ssid != "") {
    Serial.print("Intentando con la última red guardada: ");
    Serial.print(last_ssid);

    WiFi.begin(last_ssid.c_str(), last_password.c_str());

    for (int i = 0; i < max_intentos; i++) {
      if (WiFi.status() == WL_CONNECTED) {
        conectado = true;
        break;
      }
      delay(500);
      Serial.print(".");
    }

    if (conectado) {
      Serial.println("\nConectado a la última red guardada.");
      Serial.print("IP: ");
      Serial.println(WiFi.localIP());
      return;
    } else {
      Serial.println("\nNo se pudo conectar a la última red guardada.");
    }
  }

  //Intenta conectarse a la red que se le cargo por formulario HTML
  Serial.print("Intentando conectar a: ");
  Serial.println(config.wifiSSID);
  WiFi.begin(config.wifiSSID, config.wifiPassword);
  for (int j = 0; j < max_intentos; j++) {
    if (WiFi.status() == WL_CONNECTED) {
      conectado = true;

      // Guardar esta red en NVS
      preferences.begin("wifi", false);
      preferences.putString("last_ssid", config.wifiSSID);
      preferences.putString("last_password", config.wifiPassword);
      preferences.end();

      Serial.println("\nConexión exitosa.");
      Serial.print("IP: ");
      Serial.println(WiFi.localIP());
      return;
    }
    delay(500);
    Serial.print(".");
  }

  // Intentar conectarse con las redes del vector
  for (int i = 0; i < numRedes; i++) {
    const char* ssid = redes[i][0];
    const char* password = redes[i][1];

    Serial.print("Intentando conectar a redes standars: ");
    Serial.println(ssid);

    WiFi.begin(ssid, password);

    for (int j = 0; j < max_intentos; j++) {
      if (WiFi.status() == WL_CONNECTED) {
        conectado = true;

        // Guardar esta red en NVS
        preferences.begin("wifi", false);
        preferences.putString("last_ssid", ssid);
        preferences.putString("last_password", password);
        preferences.end();

        Serial.println("\nConexión exitosa.");
        Serial.print("IP: ");
        Serial.println(WiFi.localIP());
        return;
      }
      delay(500);
      Serial.print(".");
    }

    if (!conectado) {
      Serial.println("\nNo se pudo conectar a esta red.");
    }
  }

  // Si no se conecta a ninguna red, reinicia el ESP32
  Serial.println("Error: No se pudo conectar a ninguna red, reiniciando...");
  ESP.restart();
}

void configuracionPines(){
  pinMode(FASE_R, OUTPUT); // D1 salida digital activa optoacopladores 
  digitalWrite(FASE_R, HIGH);
  pinMode(FASE_S, OUTPUT); // D6 salida digital activa optoacopladores
  digitalWrite(FASE_S, HIGH);
  pinMode(FASE_T, OUTPUT); // D5 salida digital activa optoacopladores
  digitalWrite(FASE_T, HIGH);
  pinMode(LED_ROJO, OUTPUT); // Sensor encendido
  pinMode(DETECTOR_1, OUTPUT); //  Detector 1
  digitalWrite(DETECTOR_1, LOW);
  pinMode(DETECTOR_2, OUTPUT); // Detector 2
  digitalWrite(DETECTOR_2, LOW);
  pinMode(DETECTOR_3, OUTPUT); // Detector 3
  digitalWrite(DETECTOR_3, LOW);
  pinMode(DETECTOR_4, OUTPUT); // Detector 4
  digitalWrite(DETECTOR_4, LOW);
  pinMode(RELE_1, OUTPUT); // RELE
  digitalWrite(RELE_1, LOW);
  pinMode(RELE_2, OUTPUT); // RELE 2
  digitalWrite(RELE_2, LOW);
}

void parpadearLed(void *pvParameters) {
  for (;;) {
    digitalWrite(LED_ROJO,HIGH);
    vTaskDelay(1000 / portTICK_PERIOD_MS);
    digitalWrite(LED_ROJO,LOW);
    vTaskDelay(1000 / portTICK_PERIOD_MS);
  }
}

void reconnect() {
  Serial.print("Intentando conectar a MQTT...");
  if ("ESP32S2Client") {
    Serial.println("conectado");
  } else {
    Serial.print("fallo, rc=");
    Serial.print(client.state());
    ESP.restart();
    delay(5000);
  }
}

void leerDHT11(){
    temperatura[0] = dht1.readTemperature();
    humedad[0] = dht1.readHumidity();
    if(isnan(temperatura[0])){
      temperatura[0] = ERROR;
      humedad[0] = ERROR;
    }
    delay(2000);

    temperatura[1] = dht2.readTemperature();
    humedad[1] = dht2.readHumidity();
    if(isnan(temperatura[1])){
      temperatura[1] = ERROR;
      humedad[1] = ERROR;
    }
    delay(2000);

    temperatura[2] = dht3.readTemperature();
    humedad[2] = dht3.readHumidity();
    if(isnan(temperatura[2])){
      temperatura[2] = ERROR;
      humedad[2] = ERROR;
    }
    delay(2000);

    temperatura[3] = dht4.readTemperature();
    humedad[3] = dht4.readHumidity();
    if(isnan(temperatura[3])){
      temperatura[3] = ERROR;
      humedad[3] = ERROR;
    }
    delay(2000); 

    printf("Temperatura 1: %f, Humedad 1 : %f\n",temperatura[0],humedad[0]);
    printf("Temperatura 2: %f, Humedad 2 : %f\n",temperatura[1],humedad[1]);
    printf("Temperatura 3: %f, Humedad 3 : %f\n",temperatura[2],humedad[2]);
    printf("Temperatura 4: %f, Humedad 4 : %f\n",temperatura[3],humedad[3]);
  }

void leerDS18B20(){
  // Solicitar temperatura a cada sensor
  sensors1.requestTemperatures();
  sensors2.requestTemperatures();
  sensors3.requestTemperatures();
  sensors4.requestTemperatures();

  // Leer y mostrar las temperaturas
  temperatura[0] = sensors1.getTempCByIndex(0);
  temperatura[1] = sensors2.getTempCByIndex(0);
  temperatura[2] = sensors3.getTempCByIndex(0);
  temperatura[3] = sensors4.getTempCByIndex(0);

  Serial.print("Temperatura Sensor 1: ");
  Serial.println(temperatura[0]);
  Serial.print("Temperatura Sensor 2: ");
  Serial.println(temperatura[1]);
  Serial.print("Temperatura Sensor 3: ");
  Serial.println(temperatura[2]);
  Serial.print("Temperatura Sensor 4: ");
  Serial.println(temperatura[3]);
}

void lecturaPzems(){
  // ######## FASE R ########
    digitalWrite(FASE_S, HIGH);
    digitalWrite(FASE_T, HIGH);
    digitalWrite(FASE_R, HIGH);
    delay(2000);
    //pzem.resetEnergy();
    digitalWrite(FASE_R, LOW);
  
    delay(3000);
    //printf("FASE R\n");
    voltaje[0] = pzem.voltage();
    voltaje[0] = voltaje[0]*factorVoltaje;
    delay(1000);
    corriente[0] = pzem.current()*factorBobina;
  
    if(isnan(voltaje[0])){
      voltaje[0] = ERROR;
      corriente[0] = ERROR;
    }
  
    printf("Voltaje Fase R: %f \n",voltaje[0]);
    printf("Corriente Fase R: %f\n",corriente[0]);
  
  // ######## FASE S ########
    digitalWrite(FASE_S, HIGH);
    digitalWrite(FASE_T, HIGH);
    digitalWrite(FASE_R, HIGH);
    delay(2000);
    //pzem.resetEnergy();
    digitalWrite(FASE_S, LOW);
  
  
    delay(3000);
    //printf("FASE S\n");
    voltaje[1] = pzem.voltage();
    voltaje[1] = voltaje[1]*factorVoltaje;
    delay(1000);
    corriente[1] = pzem.current()*factorBobina;
  
    if(isnan(voltaje[1])){
      voltaje[1] = ERROR;
      corriente[1] = ERROR;
    }
  
    printf("Voltaje Fase S: %f\n",voltaje[1]);
    printf("Corriente Fase S: %f\n",corriente[1]);
  
  
  // ######## FASE T ########
    digitalWrite(FASE_S, HIGH);
    digitalWrite(FASE_T, HIGH);
    digitalWrite(FASE_R, HIGH);
    delay(2000);
    //pzem.resetEnergy();
    digitalWrite(FASE_T, LOW);
  
  
    delay(3000);
    //printf("FASE T\n");
    voltaje[2] = pzem.voltage();
    voltaje[2] = voltaje[2]*factorVoltaje;
    delay(1000);
    corriente[2] = pzem.current()*factorBobina;
  
    if(isnan(voltaje[2])){
      voltaje[2] = ERROR;
      corriente[2] = ERROR;
    }
  
    printf("Voltaje Fase T: %f\n",voltaje[2]);
    printf("Corriente Fase T: %f\n",corriente[2]);
  
    digitalWrite(FASE_S, HIGH);
    digitalWrite(FASE_T, HIGH);
    digitalWrite(FASE_R, HIGH);
    delay(2000);
    printf("******Fin de Leer Pzem******\n");
  }

  void enviarDatosMQTT(){
    char topicBuffer[100]; // Buffer for the topic
    char payloadBuffer[20]; // Buffer for the payload

    if (!WiFi.isConnected()) {
      Serial.println("Wi-Fi desconectado. Intentando reconectar...");
      //wifiInit();
      wifiInit(redes, maxWifiSSID, maxWifiRetry);
    }
  
    if (!client.connected()) {
      reconnect();
    }
    //Se debe colocar el numero de cliente correspondiente al modulo utilizado
    if (!client.loop())
      client.connect(CLIENT_ID.c_str(), mqtt_user, mqtt_pass);
  
    sprintf(topicBuffer, "EMSETEC/%s/FASER/VOLTAJE", EQUIPO.c_str());
    sprintf(payloadBuffer, "%.2f", voltaje[0]);
    client.publish(topicBuffer, payloadBuffer);
    delay(250);

    sprintf(topicBuffer, "EMSETEC/%s/FASES/VOLTAJE", EQUIPO.c_str());
    sprintf(payloadBuffer, "%.2f", voltaje[1]);
    client.publish(topicBuffer, payloadBuffer);
    delay(250);

    sprintf(topicBuffer, "EMSETEC/%s/FASET/VOLTAJE", EQUIPO.c_str());
    sprintf(payloadBuffer, "%.2f", voltaje[2]);
    client.publish(topicBuffer, payloadBuffer);
    delay(250);

    sprintf(topicBuffer, "EMSETEC/%s/FASER/CORRIENTE", EQUIPO.c_str());
    sprintf(payloadBuffer, "%.2f", corriente[0]);
    client.publish(topicBuffer, payloadBuffer);
    delay(250);
    
    sprintf(topicBuffer, "EMSETEC/%s/FASES/CORRIENTE", EQUIPO.c_str());
    sprintf(payloadBuffer, "%.2f", corriente[1]);
    client.publish(topicBuffer, payloadBuffer);
    delay(250);

    sprintf(topicBuffer, "EMSETEC/%s/FASET/CORRIENTE", EQUIPO.c_str());
    sprintf(payloadBuffer, "%.2f", corriente[2]);
    client.publish(topicBuffer, payloadBuffer);
    delay(250);
  
    if(temperatura[0] > RANGO_INF && temperatura[0] < RANGO_SUP){
      sprintf(topicBuffer, "EMSETEC/%s/SENSOR1/TEMPERATURA", EQUIPO.c_str());
      sprintf(payloadBuffer, "%.2f", temperatura[0]);
      client.publish(topicBuffer, payloadBuffer);
      delay(250);
  }
  if(temperatura[1] > RANGO_INF && temperatura[1] < RANGO_SUP){
      sprintf(topicBuffer, "EMSETEC/%s/SENSOR2/TEMPERATURA", EQUIPO.c_str());
      sprintf(payloadBuffer, "%.2f", temperatura[1]);
      client.publish(topicBuffer, payloadBuffer);
      delay(250);
  }
  if(temperatura[2] > RANGO_INF && temperatura[2] < RANGO_SUP){
      sprintf(topicBuffer, "EMSETEC/%s/SENSOR3/TEMPERATURA", EQUIPO.c_str());
      sprintf(payloadBuffer, "%.2f", temperatura[2]);
      client.publish(topicBuffer, payloadBuffer);
      delay(250);
  }
  if(temperatura[3] > RANGO_INF && temperatura[3] < RANGO_SUP){
      sprintf(topicBuffer, "EMSETEC/%s/SENSOR4/TEMPERATURA", EQUIPO.c_str());
      sprintf(payloadBuffer, "%.2f", temperatura[3]);
      client.publish(topicBuffer, payloadBuffer);
      delay(250);
  }

  if(humedad[0] > RANGO_INF && humedad[0] < RANGO_SUP){
      sprintf(topicBuffer, "EMSETEC/%s/SENSOR1/HUMEDAD", EQUIPO.c_str());
      sprintf(payloadBuffer, "%.2f", humedad[0]);
      client.publish(topicBuffer, payloadBuffer);
      delay(250);
  }
  if(humedad[1] > RANGO_INF && humedad[1] < RANGO_SUP){
      sprintf(topicBuffer, "EMSETEC/%s/SENSOR2/HUMEDAD", EQUIPO.c_str());
      sprintf(payloadBuffer, "%.2f", humedad[1]);
      client.publish(topicBuffer, payloadBuffer);
      delay(250);
  }
  if(humedad[2] > RANGO_INF && humedad[2] < RANGO_SUP){
      sprintf(topicBuffer, "EMSETEC/%s/SENSOR3/HUMEDAD", EQUIPO.c_str());
      sprintf(payloadBuffer, "%.2f", humedad[2]);
      client.publish(topicBuffer, payloadBuffer);
      delay(250);
  }
  if(humedad[3] > RANGO_INF && humedad[3] < RANGO_SUP){
      sprintf(topicBuffer, "EMSETEC/%s/SENSOR4/HUMEDAD", EQUIPO.c_str());
      sprintf(payloadBuffer, "%.2f", humedad[3]);
      client.publish(topicBuffer, payloadBuffer);
      delay(250);
  }
    
    //client.publish("EMSETEC/" +EQUIPO+ "/DETECTOR1/ESTADO:", String(detector1).c_str());delay(250);
    //client.publish("EMSETEC/" +EQUIPO+ "/DETECTOR2/ESTADO:", String(detector2).c_str());delay(250);
    //detector3 = (detector3 == "ON") ? "OFF" : "ON";
    //client.publish("EMSETEC/" +EQUIPO+ "/DETECTOR1/ESTADO:", String(detector1).c_str());delay(250);
    //client.publish("EMSETEC/" +EQUIPO+ "/DETECTOR2/ESTADO:", String(detector2).c_str());delay(250);
    //client.publish("EMSETEC/" +EQUIPO+ "/DETECTOR3/ESTADO:", String(detector3).c_str());delay(250);
    //client.publish("EMSETEC/" +EQUIPO+ "/DETECTOR4/ESTADO:", String(detector4).c_str());delay(250);
  
    //client.publish("EMSETEC/" +EQUIPO+ "/DETECTOR5/ESTADO:", String(detector1).c_str());delay(250);
    //client.publish("EMSETEC/" +EQUIPO+ "/DETECTOR6/ESTADO:", String(detector2).c_str());delay(250);
  
    //client.publish("EMSETEC/" +EQUIPO+ "/AD3/NIVELAGUA:", NA); // Nivel de Inundacion
    //client.publish("EMSETEC/" +EQUIPO+ "/SENSOR1/COMBUSTIBLE:", String(nivelTanque2m).c_str());delay(250); //Nivel de Tanque de Agua
    //client.publish("EMSETEC/" +EQUIPO+ "/SENSOR2/COMBUSTIBLE:", String(nivelTanque2m_sensor2).c_str());delay(250); //Nivel de Tanque de Agua
    //client.publish("EMSETEC/SERIE10/AD1/COMBUSTIBLE:", Comb);delay(250);
    //client.publish("EMSETEC/SERIE10/AD2/VOLTAJE:", Bat);delay(250);
  
  }

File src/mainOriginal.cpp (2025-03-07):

//Librerias a utilizar en en el programa
#include <Arduino.h>
#include <WiFi.h>
#include <PubSubClient.h>
#include "DHT.h"
#include <PZEM004Tv30.h>
#include <OneWire.h>
#include <DallasTemperature.h>
#include <Preferences.h>
#include "Adafruit_MQTT.h"
#include "Adafruit_MQTT_Client.h"

#define PZEM_RX_PIN 16
#define PZEM_TX_PIN 17
#define PZEM_SERIAL Serial2

#define DHT1 15 //15
#define DHT2 2
#define DHT3 0
#define DHT4 4

#define DETECTOR_1 5
#define DETECTOR_2 18
#define DETECTOR_3 19
#define DETECTOR_4 21

#define RELE_1 25
#define RELE_2 26
#define ADC_1 32
#define ADC_2 36

#define ERROR 0

//#define factor_bobina 40 //AUSTRIA
//#define factor_bobina 2 // BOBINA AZUL

#define FASE_R 12
#define FASE_S 14
#define FASE_T 27
#define LED_ROJO 33


//El largo de este vector como minimo tiene que ser el tiempo de envio en segundos x2, porque leo los detectores cada 500ms
#define VECTOR_DETECTOR 250 
#define VECTOR 4

PZEM004Tv30 pzem(PZEM_SERIAL, PZEM_RX_PIN, PZEM_TX_PIN);
Preferences preferences;

//Definiciones del sensor de temperatura y humedad
#define DHTTYPE DHT11   // DHT 11
#define DHTTYPE2 DHT11   // DHT 11-2
#define DHTTYPE3 DHT11   // DHT 11-3
#define DHTTYPE4 DHT11   // DHT 11-4
//#########################################################################################
//#########################################################################################
//#########################################################################################
//#########################################################################################
#define SENSOR_DHT
//#define SENSOR_DS18B20

//#########################################################################################
//#########################################################################################
//#########################################################################################
//#########################################################################################
#ifdef SENSOR_DHT
    // Creamos los objetos para DHT
    DHT dht1(DHT1, DHTTYPE);
    DHT dht2(DHT2, DHTTYPE2);
    DHT dht3(DHT3, DHTTYPE3);
    DHT dht4(DHT4, DHTTYPE4);
#elif defined(SENSOR_DS18B20)
    // Configuración para cada sensor DS18B20
    OneWire oneWire1(DHT1);
    OneWire oneWire2(DHT2);
    OneWire oneWire3(DHT3);
    OneWire oneWire4(DHT4);

    DallasTemperature sensors1(&oneWire1);
    DallasTemperature sensors2(&oneWire2);
    DallasTemperature sensors3(&oneWire3);
    DallasTemperature sensors4(&oneWire4);
#endif

//#########################################################################################
//#########################################################################################
//#########################################################################################
//#########################################################################################
//#########################################################################################

#define EQUIPO "SERIE42"
#define ESP_CLIENT_NAME espClient42
WiFiClient ESP_CLIENT_NAME;
PubSubClient client(ESP_CLIENT_NAME);
const char* CLIENT_ID = "espClient42";
float factorVoltaje = 1;
//float factorVoltaje = 1;

//float factor_bobina = 1;
float factor_bobina = 2;
//float factor_bobina = 40; //Austria bobinas negras abiertas
//float factor_bobina = 100;
//float factor_bobina = 400;

int maxWifiSSID = 3;
int maxWifiRetry = 10;

const char* redes[3][2] = {
    {"e-Invitados", "Edenor2022$"},
    {"EMSETEC4G", "IOT2024EMSETEC"},
    {"HUAWEI_311_1B94", "Maxpower1995"}
  };

/*  const char* redes[8][2] = {
    {"e-Invitados", "Edenor2022$"},
    {"EMSETEC4G", "IOT2024EMSETEC"},
    {"HUAWEI_ESP32", "Maxpower"},
    {"DECO-Wifi117", "0103371008"},
    {"HUAWEI_311_1B94", "Maxpower1995"},
    {"HUAWEI_311_90BD", "GRQLRRNAL0B"},
    {"InternetCLARO0838", "6BA4B904"},
    {"EMSETEC-2.4GHz", "33710081099"}
  };  */


//#########################################################################################
//#########################################################################################
//#########################################################################################
//#########################################################################################
//#########################################################################################

//Incluir la direccion del servidor MQTT
const char* mqtt_server = "143.198.66.52";// Broker EDENOR
//const char* mqtt_server = "143.244.186.22"; // Broker Prueba


const char* mqtt_user = "emsetec";
const char* mqtt_pass = "84705200";

//Variables para enviar datos por MQTT
const unsigned long TIEMPO_DE_ENVIO = 60000;  
const unsigned long RESET = 3600000*2;  // 1 hora en milisegundos
unsigned long ultimoEnvio = 0;  // Tiempo de la última ejecución
unsigned long tiempoActual = 0;
unsigned long tiempoReset = 0;



//Si se usa el arduino IDE quiza hay que borrar estas definiciones de funciones
void wifiInit(const char* redes[][2], int num_redes, int max_intentos);
void reconnect();
void lecturaPzems();
void leerDHT11();
void leerDetectores(void *parameter);
void seteoDetector();
void resetVectorDetectores();
void enviarDatosMQTT();
void nivelTanquedeAgua2m();
void parpadearLed(void *pvParameters);
void leerNA();
void leerCombustibleGarin();
void leerBateriaGarin();
void nivelTanquedeAgua2m_sensor2();
void leerDS18B20();
void stopWiFi();

float voltajeR = 0;
float voltajeS = 0;
float voltajeT = 0;

float corrienteR = 0;
float corrienteS = 0;
float corrienteT = 0;

float dhtTemperatura1 = 0;
float dhtHumedad1 = 0;
float dhtTemperatura2 = 0;
float dhtHumedad2 = 0;
float dhtTemperatura3 = 0;
float dhtHumedad3 = 0;
float dhtTemperatura4 = 0;
float dhtHumedad4 = 0;

int nivelTanque2m = 0;
static char NA[7];
static char Bat[7];
static char Comb[7];
int cont = 0;
int contador_tension = 0;

String detector1 = "OFF";
String detector2 = "OFF";
String detector3 = "OFF";
String detector4 = "OFF";

String vectorDetector1[VECTOR_DETECTOR];
String vectorDetector2[VECTOR_DETECTOR];
String vectorDetector3[VECTOR_DETECTOR];
String vectorDetector4[VECTOR_DETECTOR];

int contador = 0;
int contadorPzem = 0;
bool tareaActiva = true; 
bool firstTime = true;
int nivelTanque2m_sensor2 = 0;
//La bobina del pzem queda iugal
//La bobina azul se multiplica x 2
//La bobinas de 1000A se multiplican x100

const float referenceVoltage = 3.3;  // Voltaje de referencia del ADC (3.3 V para ESP32)
const int adcResolution = 4095;      // Resolución del ADC del ESP32 (12 bits)
const float resistorRatio = (82.0 + 10.0) / 10.0;  // Relación del divisor resistivo
const int numSamples = 20;
const float calibrationFactor = 1.02;  // Factor de ajuste basado en mediciones reales
//const float a = 1.210;  // Pendiente
//const float b = 1.41;   // Intersección



//-------------------- VOID SETUP -------------
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

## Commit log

2025-02-19 Primer commit
    [MODULO-IoT-B_Cu.gbr, MODULO-IoT-B_Mask.gbr, MODULO-IoT-B_Paste.gbr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]
2025-02-26 | 2.0 | 26/02/2025 | Server HTTP funcionando |
    [csv_filtrado_mes_1_año_25.csv, tabla_filtrado_mes_1_año_25.csv, tabla_mesyano.csv]
